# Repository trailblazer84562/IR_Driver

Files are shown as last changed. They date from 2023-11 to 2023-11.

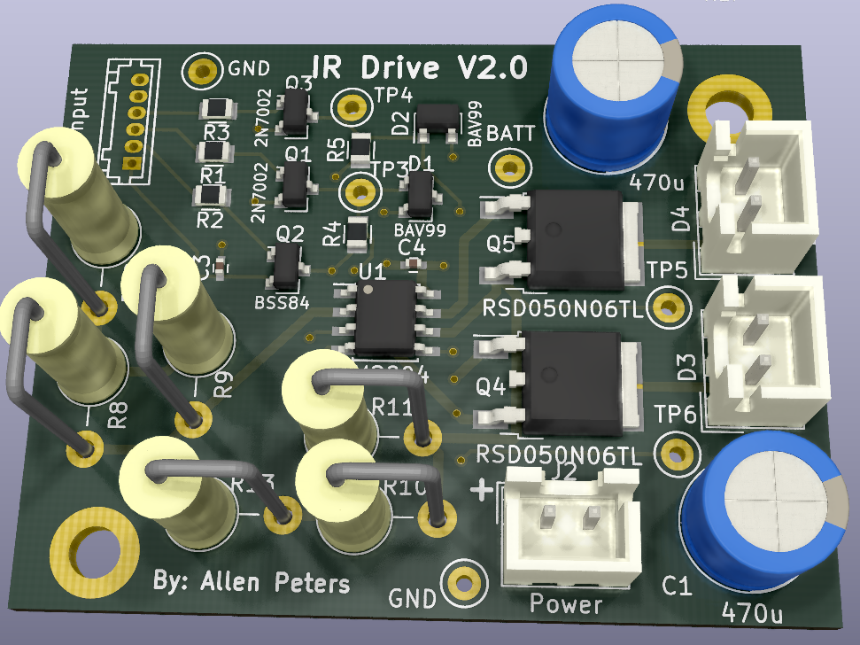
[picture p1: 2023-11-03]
EmitterDriverV2/EmitterV2.PNG

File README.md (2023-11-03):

# IR_Driver

<!-- Designed by Allen Peters

There are two design in here

The Emitter V2 is a dual IR driver
If I recall, the simulation and part selection is targetting ~0.9A
Works with 2S lipo, 6AA or 6NiMh batteries and performance should be voltage independent

The 360 IR TX and RX design is based off the Emitter V2
It targets a lower current (~200mA?) and drives 8 TSAL 7400 LEDs in a 360 degree pattern
It also has 4 IR receivers, also for a 360 degree pickup pattern -->

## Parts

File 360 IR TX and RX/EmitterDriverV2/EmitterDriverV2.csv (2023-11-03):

Source: | E:\Google Drive 2\KiCAD\Lantern Transmit Receive\EmitterDriverV2\EmitterDriverV2.kicad_sch
Date: | 7/3/2022 9:09:35 PM
Tool: | Eeschema (6.0.1)
Generator: | C:\Program Files\KiCad\6.0\bin\scripting\plugins/bom_csv_grouped_by_value.py
Component Count: | 50
Individual Components:
Item | Qty | Reference(s) | Value | LibPart | Footprint | Datasheet
 |  | C1 | 4.7u | Device:C | Capacitor_SMD:C_0805_2012Metric | ~
 |  | C2 | 470u | Device:CP | Capacitors_THT:CP_Radial_D8.0mm_P3.50mm
 |  | C3 | 2.2u | Device:C | Capacitors_SMD:C_0402 | ~
 |  | C4 | 2.2u | Device:C | Capacitors_SMD:C_0402 | ~
 |  | D1 | BAV99 | Diode:BAV99 | TO_SOT_Packages_SMD:SOT-23 | https://assets.nexperia.com/documents/data-sheet/BAV99_SER.pdf
 |  | D2 | BAV99 | Diode:BAV99 | TO_SOT_Packages_SMD:SOT-23 | https://assets.nexperia.com/documents/data-sheet/BAV99_SER.pdf
 |  | D3 | LED1 | Device:LED | LED_THT:LED_D5.0mm | ~
 |  | D4 | LED1 | Device:LED | LED_THT:LED_D5.0mm | ~
 |  | D5 | LED1 | Device:LED | LED_THT:LED_D5.0mm | ~
 |  | D6 | LED1 | Device:LED | LED_THT:LED_D5.0mm | ~
 |  | D7 | LED1 | Device:LED | LED_THT:LED_D5.0mm | ~
 |  | D8 | LED1 | Device:LED | LED_THT:LED_D5.0mm | ~
 |  | D9 | LED1 | Device:LED | LED_THT:LED_D5.0mm | ~
 |  | D10 | LED1 | Device:LED | LED_THT:LED_D5.0mm | ~
 |  | H1 | MountingHole | Mechanical:MountingHole | MountingHole:MountingHole_3.2mm_M3 | ~
 |  | H2 | MountingHole | Mechanical:MountingHole | MountingHole:MountingHole_3.2mm_M3 | ~
 |  | J1 | Input | Connector_Generic:Conn_01x06 | Connectors_Hirose:Hirose_DF13-06P-1.25DSA_06x1.25mm_Straight | ~
 |  | J2 | Power | Connector_Generic:Conn_01x02 | Connectors_JST:JST_XH_B02B-XH-A_02x2.50mm_Straight | ~
 |  | Q1 | 2N7002 | Transistor_FET:2N7002 | TO_SOT_Packages_SMD:SOT-23 | https://www.onsemi.com/pub/Collateral/NDS7002A-D.PDF
 |  | Q2 | BSS84 | Transistor_FET:BSS84 | TO_SOT_Packages_SMD:SOT-23 | http://assets.nexperia.com/documents/data-sheet/BSS84.pdf
 |  | Q3 | 2N7002 | Transistor_FET:2N7002 | TO_SOT_Packages_SMD:SOT-23 | https://www.onsemi.com/pub/Collateral/NDS7002A-D.PDF
 |  | Q4 | RSD050N06TL | Device:Q_NMOS_GDS | TO_SOT_Packages_SMD:TO-252-2 | ~
 |  | Q5 | RSD050N06TL | Device:Q_NMOS_GDS | TO_SOT_Packages_SMD:TO-252-2 | ~
 |  | R1 | 100 | Device:R | Resistor_SMD:R_0805_2012Metric | ~
 |  | R2 | 0 ohm | Device:R | Resistors_SMD:R_0805 | ~
 |  | R3 | 0 ohm | Device:R | Resistors_SMD:R_0805 | ~
 |  | R4 | 0 ohm | Device:R | Resistors_SMD:R_0805 | ~
 |  | R5 | 1k | Device:R | Resistors_SMD:R_0805 | ~
 |  | R6 | 1k | Device:R | Resistors_SMD:R_0805 | ~
 |  | R7 | 1k | Device:R | Resistors_SMD:R_0805 | ~
 |  | R8 | 1k | Device:R | Resistors_SMD:R_0805 | ~
 |  | R9 | 1 ohm | Device:R | Resistor_SMD:R_0805_2012Metric | ~
 |  | R10 | 1 ohm | Device:R | Resistor_SMD:R_0805_2012Metric | ~
 |  | R11 | 1 ohm | Device:R | Resistor_SMD:R_0805_2012Metric | ~
 |  | R12 | 1 ohm | Device:R | Resistor_SMD:R_0805_2012Metric | ~
 |  | R13 | 1 ohm | Device:R | Resistor_SMD:R_0805_2012Metric | ~
 |  | R14 | 1 ohm | Device:R | Resistor_SMD:R_0805_2012Metric | ~
 |  | TP1 | VBatt | Connector:TestPoint | TestPoint:TestPoint_Keystone_5000-5004_Miniature | ~
 |  | TP2 | GND | Connector:TestPoint | TestPoint:TestPoint_Keystone_5000-5004_Miniature | ~
 |  | TP3 | TX1Set | Connector:TestPoint | TestPoint:TestPoint_Keystone_5000-5004_Miniature | ~
 |  | TP4 | TX2Set | Connector:TestPoint | TestPoint:TestPoint_Keystone_5000-5004_Miniature | ~
 |  | TP5 | TX1FB | Connector:TestPoint | TestPoint:TestPoint_Keystone_5000-5004_Miniature | ~
 |  | TP6 | TX2FB | Connector:TestPoint | TestPoint:TestPoint_Keystone_5000-5004_Miniature | ~
 |  | TP7 | GND | Connector:TestPoint | TestPoint:TestPoint_Keystone_5000-5004_Miniature | ~
 |  | TP8 | RX | Connector:TestPoint | TestPoint:TestPoint_Keystone_5000-5004_Miniature | ~
 |  | U1 | TSOP4838 | Interface_Optical:TSOP45xx | OptoDevice:Vishay_MOLD-3Pin | http://www.vishay.com/docs/82460/tsop45.pdf
 |  | U2 | TSOP4838 | Interface_Optical:TSOP45xx | OptoDevice:Vishay_MOLD-3Pin | http://www.vishay.com/docs/82460/tsop45.pdf
 |  | U3 | TSOP4838 | Interface_Optical:TSOP45xx | OptoDevice:Vishay_MOLD-3Pin | http://www.vishay.com/docs/82460/tsop45.pdf
 |  | U4 | TSOP4838 | Interface_Optical:TSOP45xx | OptoDevice:Vishay_MOLD-3Pin | http://www.vishay.com/docs/82460/tsop45.pdf
 |  | U5 | LM2904 | Amplifier_Operational:LM2904 | Housings_SOIC:SOIC-8_3.9x4.9mm_Pitch1.27mm | http://www.ti.com/lit/ds/symlink/lm358.pdf
Collated Components:
Item | Qty | Reference(s) | Value | LibPart | Footprint | Datasheet
1 | 1 | C1 | 4.7u | Device:C | Capacitor_SMD:C_0805_2012Metric | ~
2 | 1 | C2 | 470u | Device:CP | Capacitors_THT:CP_Radial_D8.0mm_P3.50mm
3 | 2 | C3, C4 | 2.2u | Device:C | Capacitors_SMD:C_0402 | ~
4 | 2 | D1, D2 | BAV99 | Diode:BAV99 | TO_SOT_Packages_SMD:SOT-23 | https://assets.nexperia.com/documents/data-sheet/BAV99_SER.pdf
5 | 8 | D3, D4, D5, D6, D7, D8, D9, D10 | LED1 | Device:LED | LED_THT:LED_D5.0mm | ~
6 | 2 | H1, H2 | MountingHole | Mechanical:MountingHole | MountingHole:MountingHole_3.2mm_M3 | ~
7 | 1 | J1 | Input | Connector_Generic:Conn_01x06 | Connectors_Hirose:Hirose_DF13-06P-1.25DSA_06x1.25mm_Straight | ~
8 | 1 | J2 | Power | Connector_Generic:Conn_01x02 | Connectors_JST:JST_XH_B02B-XH-A_02x2.50mm_Straight | ~
9 | 2 | Q1, Q3 | 2N7002 | Transistor_FET:2N7002 | TO_SOT_Packages_SMD:SOT-23 | https://www.onsemi.com/pub/Collateral/NDS7002A-D.PDF
10 | 1 | Q2 | BSS84 | Transistor_FET:BSS84 | TO_SOT_Packages_SMD:SOT-23 | http://assets.nexperia.com/documents/data-sheet/BSS84.pdf
11 | 2 | Q4, Q5 | RSD050N06TL | Device:Q_NMOS_GDS | TO_SOT_Packages_SMD:TO-252-2 | ~
12 | 1 | R1 | 100 | Device:R | Resistor_SMD:R_0805_2012Metric | ~
13 | 3 | R2, R3, R4 | 0 ohm | Device:R | Resistors_SMD:R_0805 | ~
14 | 4 | R5, R6, R7, R8 | 1k | Device:R | Resistors_SMD:R_0805 | ~
15 | 6 | R9, R10, R11, R12, R13, R14 | 1 ohm | Device:R | Resistor_SMD:R_0805_2012Metric | ~
16 | 1 | TP1 | VBatt | Connector:TestPoint | TestPoint:TestPoint_Keystone_5000-5004_Miniature | ~
17 | 2 | TP2, TP7 | GND | Connector:TestPoint | TestPoint:TestPoint_Keystone_5000-5004_Miniature | ~
18 | 1 | TP3 | TX1Set | Connector:TestPoint | TestPoint:TestPoint_Keystone_5000-5004_Miniature | ~
19 | 1 | TP4 | TX2Set | Connector:TestPoint | TestPoint:TestPoint_Keystone_5000-5004_Miniature | ~
20 | 1 | TP5 | TX1FB | Connector:TestPoint | TestPoint:TestPoint_Keystone_5000-5004_Miniature | ~
21 | 1 | TP6 | TX2FB | Connector:TestPoint | TestPoint:TestPoint_Keystone_5000-5004_Miniature | ~
22 | 1 | TP8 | RX | Connector:TestPoint | TestPoint:TestPoint_Keystone_5000-5004_Miniature | ~
23 | 4 | U1, U2, U3, U4 | TSOP4838 | Interface_Optical:TSOP45xx | OptoDevice:Vishay_MOLD-3Pin | http://www.vishay.com/docs/82460/tsop45.pdf
24 | 1 | U5 | LM2904 | Amplifier_Operational:LM2904 | Housings_SOIC:SOIC-8_3.9x4.9mm_Pitch1.27mm | http://www.ti.com/lit/ds/symlink/lm358.pdf

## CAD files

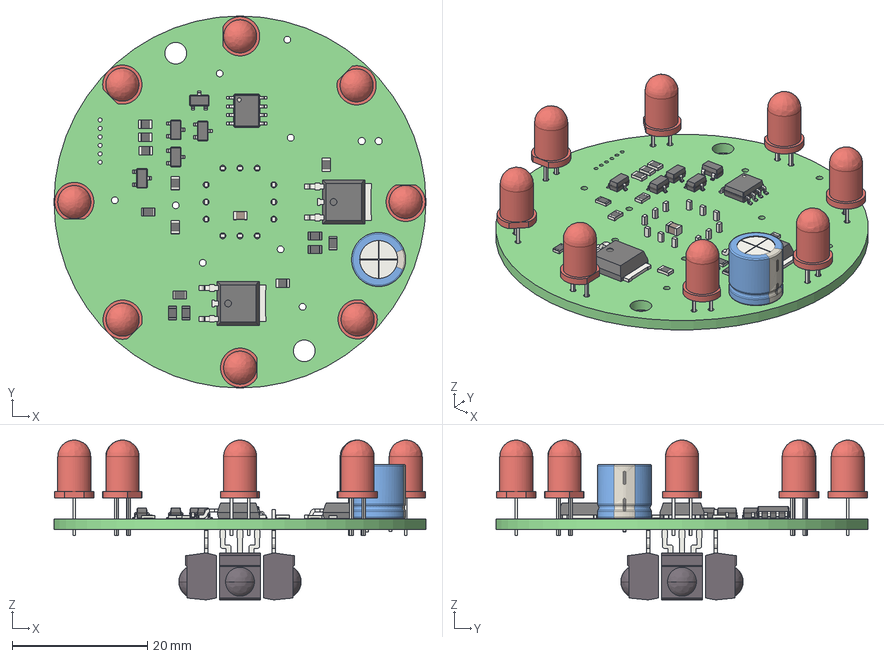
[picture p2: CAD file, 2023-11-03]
360 IR TX and RX/EmitterDriverV2/EmitterDriverV2.step
55.0 x 55.0 x 23.6 mm
EmitterDriverV2 PCB

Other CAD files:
360 IR TX and RX/EmitterDriverV2/EmitterDriverV2.ipt

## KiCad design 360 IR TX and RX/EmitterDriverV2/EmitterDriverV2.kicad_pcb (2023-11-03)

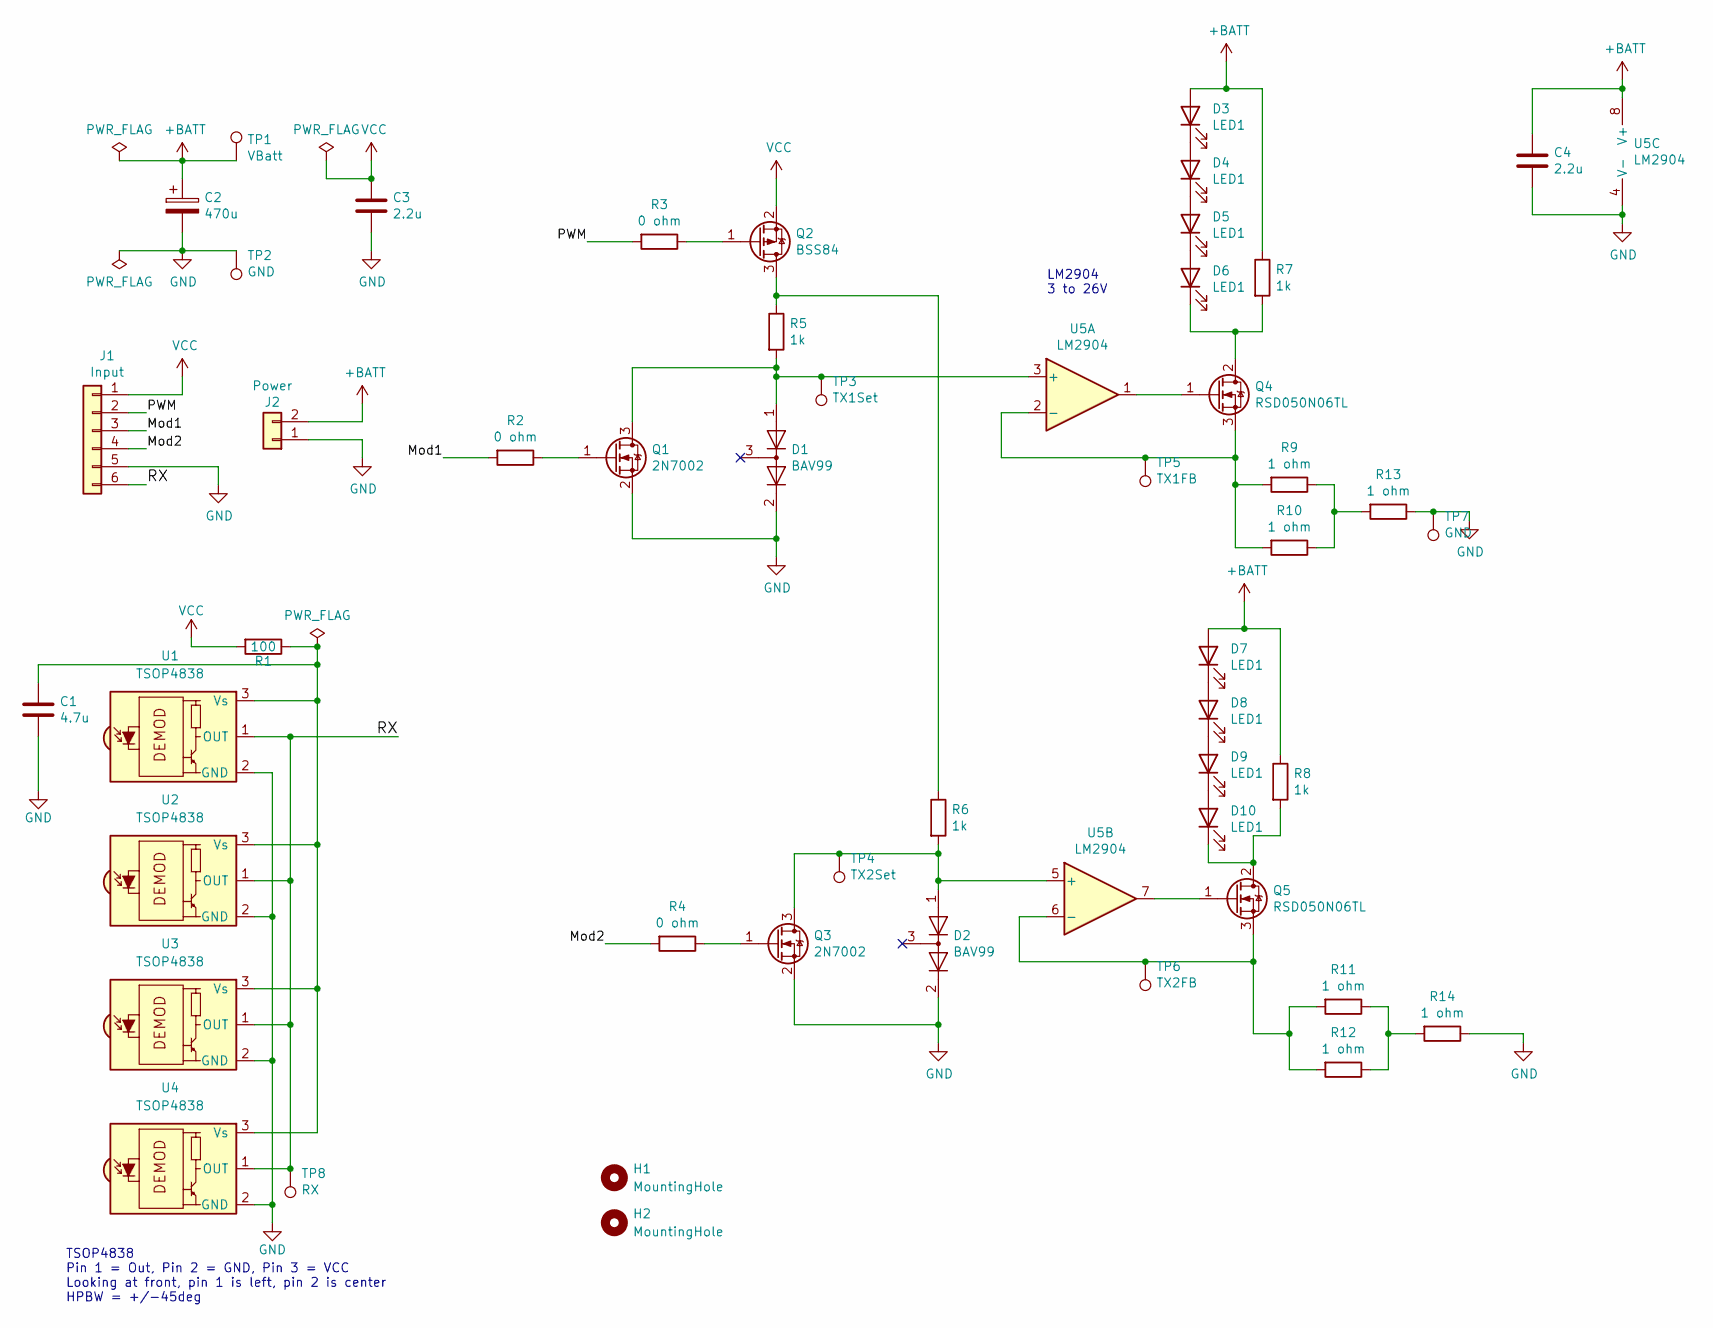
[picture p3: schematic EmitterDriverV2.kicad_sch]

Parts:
C1: 4.7u; C_0805_2012Metric
C2: 470u; CP_Radial_D8.0mm_P3.50mm
C3, C4: 2.2u; C_0402
D1, D2: BAV99; SOT-23
D3, D4, D5, D6, D7, D8, D9, D10: LED1; LED_D5.0mm
H1, H2: MountingHole; MountingHole_3.2mm_M3
J1: Input; Hirose_DF13-06P-1.25DSA_06x1.25mm_Straight
J2: Power; JST_XH_B02B-XH-A_02x2.50mm_Straight
Q1, Q3: 2N7002; SOT-23
Q2: BSS84; SOT-23
Q4, Q5: RSD050N06TL; TO-252-2
R1: 100; R_0805_2012Metric
R2, R3, R4: 0 ohm; R_0805
R5, R6, R7, R8: 1k; R_0805
R9, R10, R11, R12, R13, R14: 1 ohm; R_0805_2012Metric
TP1: VBatt; TestPoint_Keystone_5000-5004_Miniature
TP2, TP7: GND; TestPoint_Keystone_5000-5004_Miniature
TP3: TX1Set; TestPoint_Keystone_5000-5004_Miniature
TP4: TX2Set; TestPoint_Keystone_5000-5004_Miniature
TP5: TX1FB; TestPoint_Keystone_5000-5004_Miniature
TP6: TX2FB; TestPoint_Keystone_5000-5004_Miniature
TP8: RX; TestPoint_Keystone_5000-5004_Miniature
U1, U2, U3, U4: TSOP4838; Vishay_MOLD-3Pin
U5: LM2904; SOIC-8_3.9x4.9mm_Pitch1.27mm

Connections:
+BATT: C2.1, C4.1, D3.2 (A), D7.2 (A), J2.2, R7.1, R8.1, TP1.1, U5.8 (V+)
/Mod1: J1.3, R2.2
/Mod2: J1.4, R4.2
/PWM: J1.2, R3.2
/RX: J1.6, TP8.1, U1.1 (OUT), U2.1 (OUT), U3.1 (OUT), U4.1 (OUT)
GND: C1.2, C2.2, C3.2, C4.2, D1.2 (A), D2.2 (A), J1.5, J2.1, Q1.2 (S), Q3.2 (S), R13.1, R14.1, TP2.1, TP7.1, U1.2 (GND), U2.2 (GND), U3.2 (GND), U4.2 (GND), U5.4 (V-)
unnamed: C1.1, R1.1, U1.3 (Vs), U2.3 (Vs), U3.3 (Vs), U4.3 (Vs)
unnamed: D1.1 (K), Q1.3 (D), R5.2, TP3.1, U5.3 (+)
unnamed: D2.1 (K), Q3.3 (D), R6.2, TP4.1, U5.5 (+)
unnamed: D3.1 (K), D4.2 (A)
unnamed: D4.1 (K), D5.2 (A)
unnamed: D5.1 (K), D6.2 (A)
unnamed: D6.1 (K), Q4.2 (D), R7.2
unnamed: D7.1 (K), D8.2 (A)
unnamed: D8.1 (K), D9.2 (A)
unnamed: D10.1 (K), Q5.2 (D), R8.2
unnamed: D9.1 (K), D10.2 (A)
unnamed: Q1.1 (G), R2.1
unnamed: Q2.1 (G), R3.1
unnamed: Q2.3 (D), R5.1, R6.1
unnamed: Q3.1 (G), R4.1
unnamed: Q4.1 (G), U5.1
unnamed: Q4.3 (S), R9.2, R10.2, TP5.1, U5.2 (-)
unnamed: Q5.1 (G), U5.7
unnamed: Q5.3 (S), R11.2, R12.2, TP6.1, U5.6 (-)
unnamed: R9.1, R10.1, R13.2
unnamed: R11.1, R12.1, R14.2
VCC: C3.1, J1.1, Q2.2 (S), R1.2

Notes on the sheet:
TSOP4838 Pin 1 = Out, Pin 2 = GND, Pin 3 = VCC Looking at front, pin 1 is left, pin 2 is center HPBW = +/-45deg
LM2904 3 to 26V

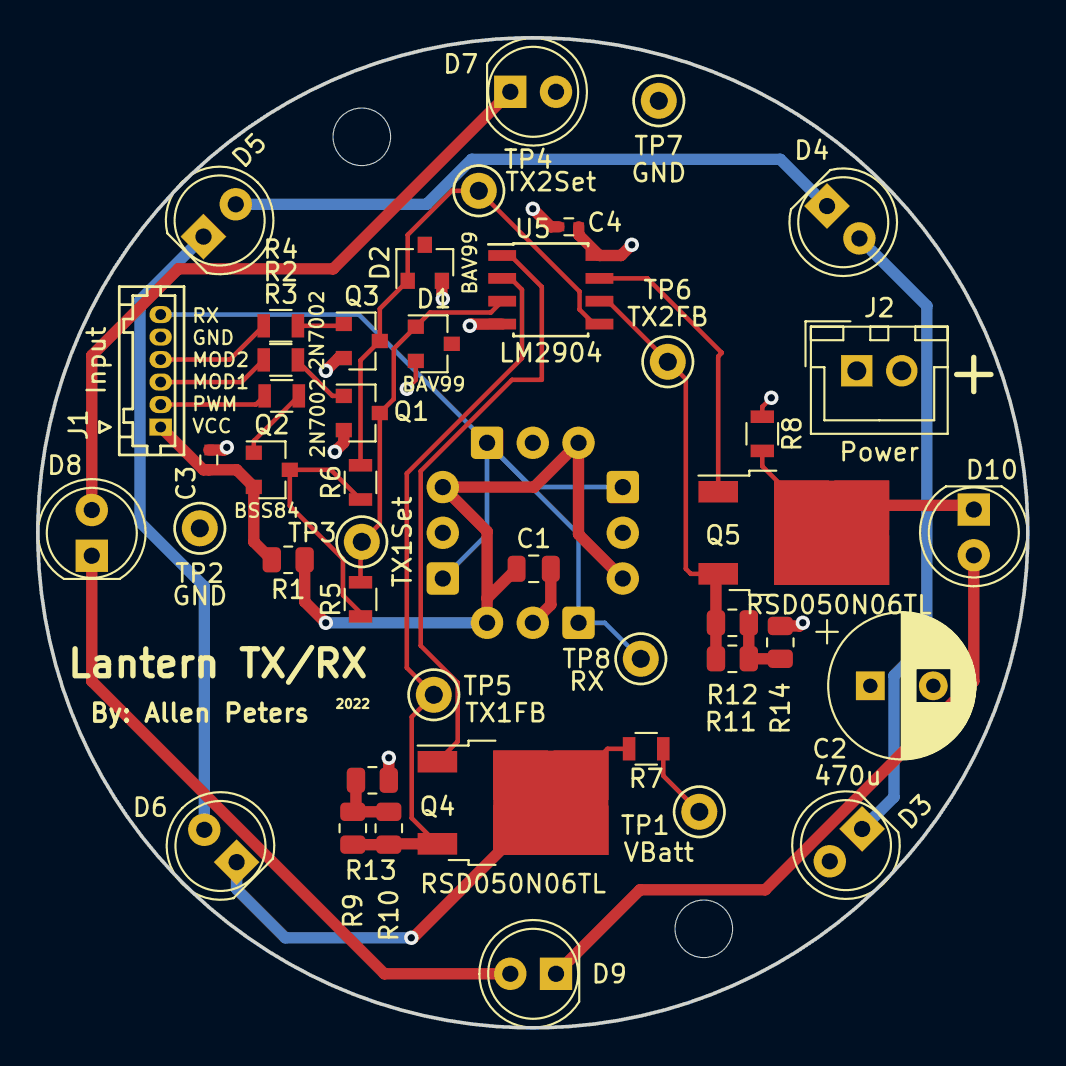
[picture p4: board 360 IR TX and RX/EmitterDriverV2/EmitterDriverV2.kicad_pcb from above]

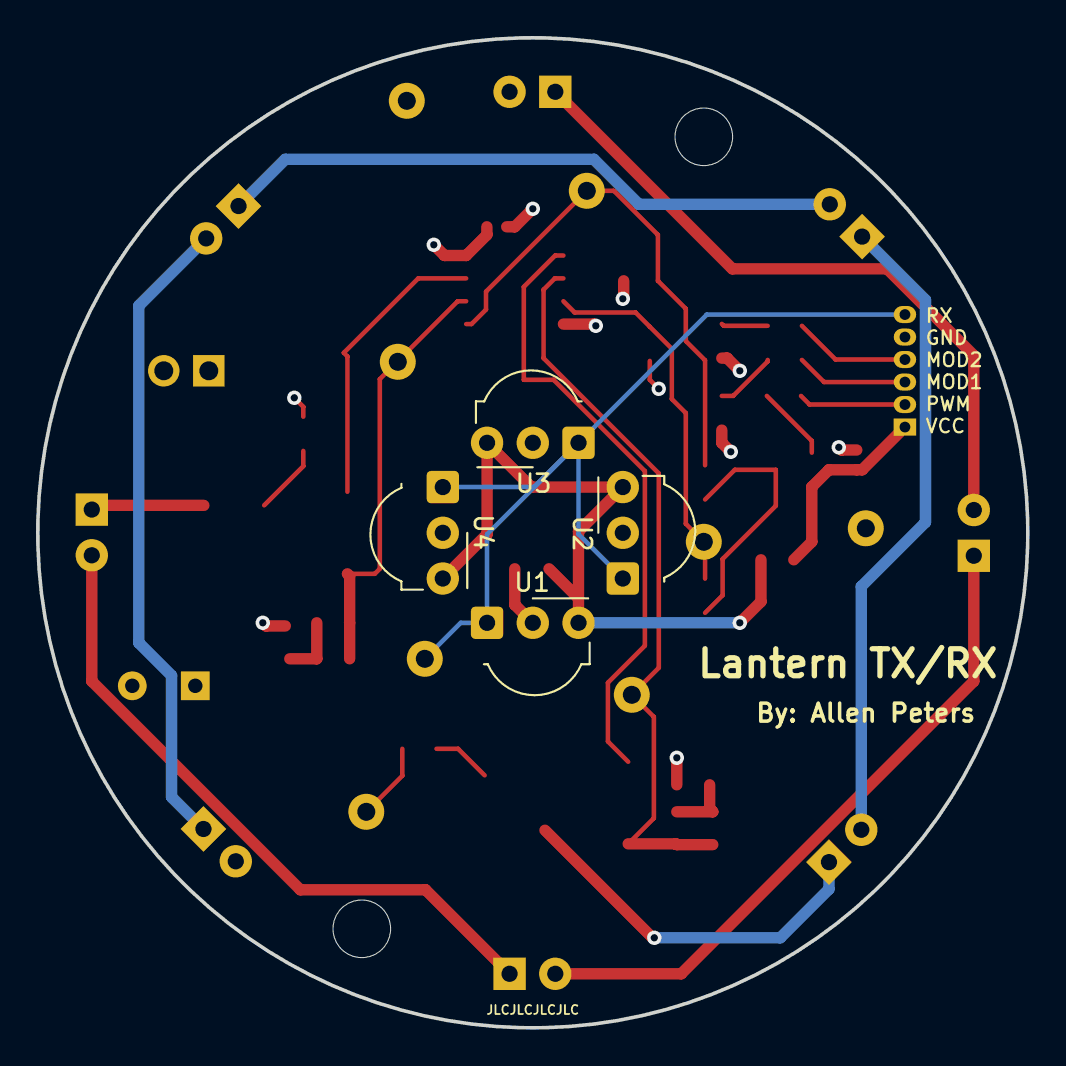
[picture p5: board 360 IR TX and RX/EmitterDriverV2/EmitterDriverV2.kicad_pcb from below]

Board: 4 copper layers, 55.0 x 55.0 mm, 50 parts (4 on the bottom side), 28 nets.

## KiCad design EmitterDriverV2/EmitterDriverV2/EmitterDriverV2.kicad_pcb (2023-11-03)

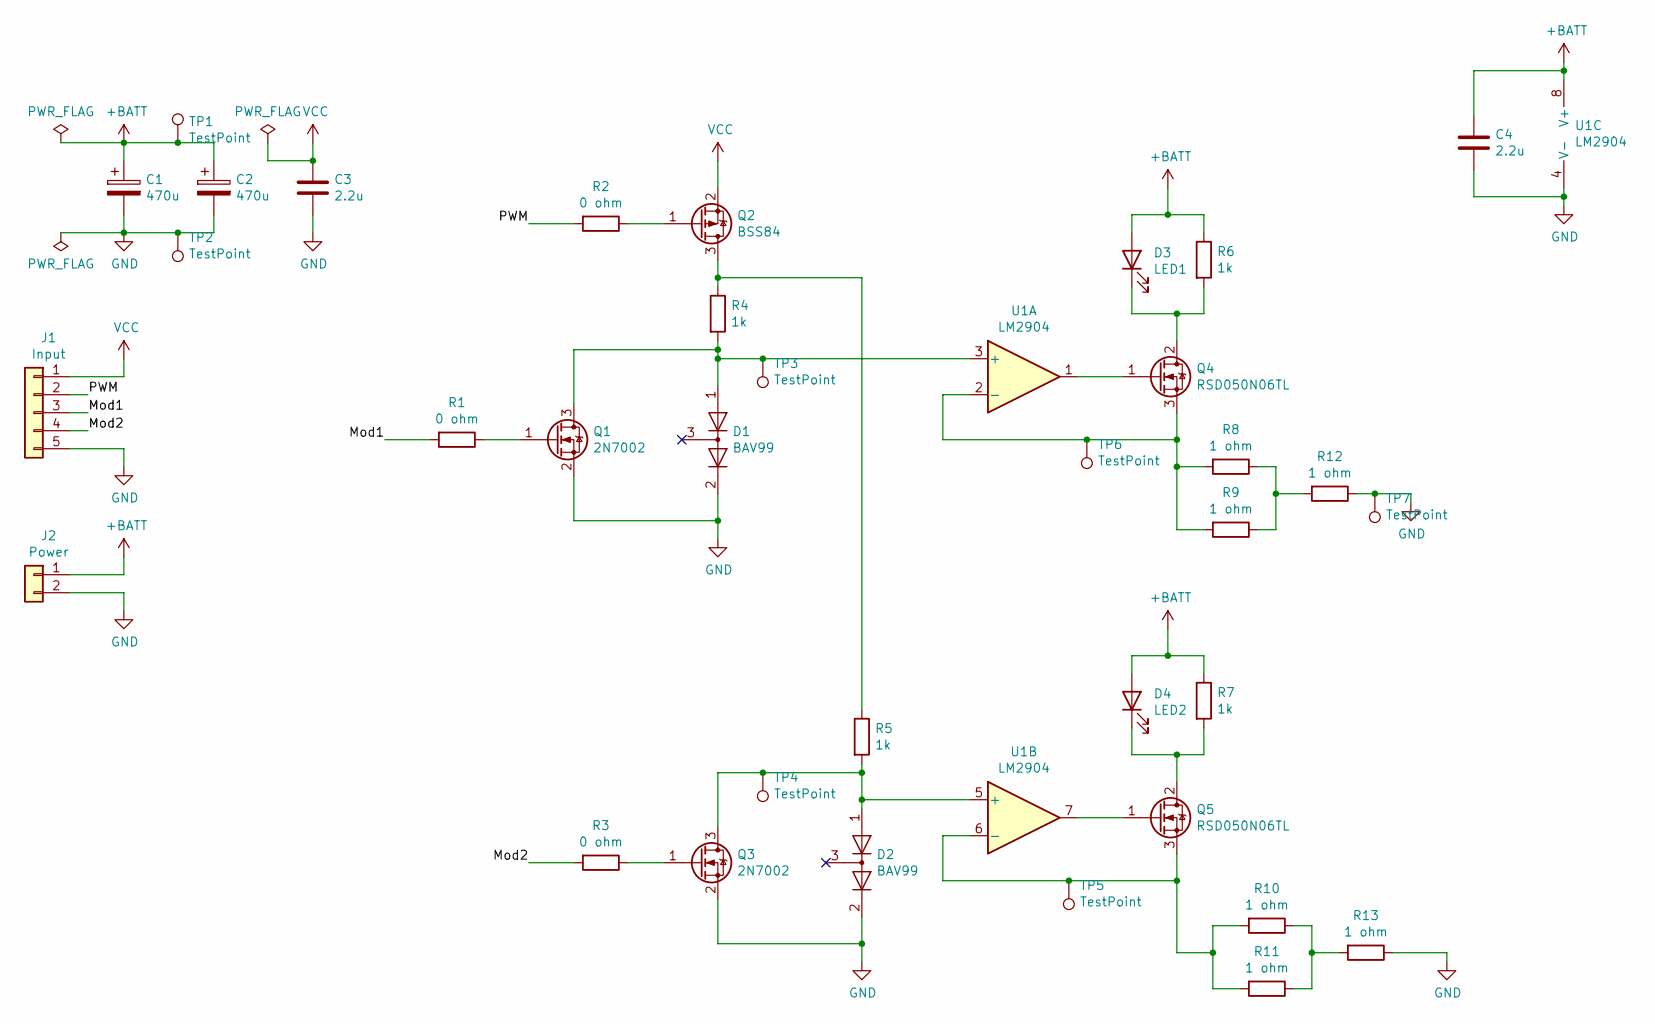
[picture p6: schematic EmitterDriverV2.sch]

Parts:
C1, C2: 470u; CP_Radial_D8.0mm_P3.50mm
C3, C4: 2.2u; C_0402
D1, D2: BAV99; SOT-23
D3: LED1; JST_XH_B02B-XH-A_02x2.50mm_Straight
D4: LED2; JST_XH_B02B-XH-A_02x2.50mm_Straight
J1: Input; Hirose_DF13-06P-1.25DSA_06x1.25mm_Straight
J2: Power; JST_XH_B02B-XH-A_02x2.50mm_Straight
Q1, Q3: 2N7002; SOT-23
Q2: BSS84; SOT-23
Q4, Q5: RSD050N06TL; TO-252-2
R1, R2, R3: 0 ohm; R_0805
R4, R5, R6, R7: 1k; R_0805
R8, R9, R10, R11, R12, R13: 1 ohm; R_Axial_DIN0414_L11.9mm_D4.5mm_P5.08mm_Vertical
TP1, TP2, TP3, TP4, TP5, TP6, TP7: TestPoint; Test_Point_Keystone_5000-5004_Miniature
U1: LM2904; SOIC-8_3.9x4.9mm_Pitch1.27mm

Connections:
+BATT: C1.1, C2.1, C4.1, D3.2 (A), D4.2 (A), J2.1, R6.1, R7.1, TP1.1, U1.8 (V+); also elsewhere on the board
/Mod1: J1.3, R1.2
/Mod2: J1.4, R3.2
/PWM: J1.2, R2.2
GND: C1.2, C2.2, C3.2, C4.2, D1.2 (A), D2.2 (A), J1.5, J2.2, Q1.2 (S), Q3.2 (S), R12.1, R13.1, TP2.1, TP7.1, U1.4 (V-); also elsewhere on the board
unnamed: D1.1 (K), Q1.3 (D), R4.2, TP3.1, U1.3 (+)
unnamed: D2.1 (K), Q3.3 (D), R5.2, TP4.1, U1.5 (+)
unnamed: D3.1 (K), Q4.2 (D), R6.2
unnamed: D4.1 (K), Q5.2 (D), R7.2
unnamed: Q1.1 (G), R1.1
unnamed: Q2.1 (G), R2.1
unnamed: Q2.3 (D), R4.1, R5.1
unnamed: Q3.1 (G), R3.1
unnamed: Q4.1 (G), U1.1
unnamed: Q4.3 (S), R8.2, R9.2, TP6.1, U1.2 (-)
unnamed: Q5.1 (G), U1.7
unnamed: Q5.3 (S), R10.2, R11.2, TP5.1, U1.6 (-)
unnamed: R10.1, R11.1, R13.2
unnamed: R8.1, R9.1, R12.2
VCC: C3.1, J1.1, Q2.2 (S)

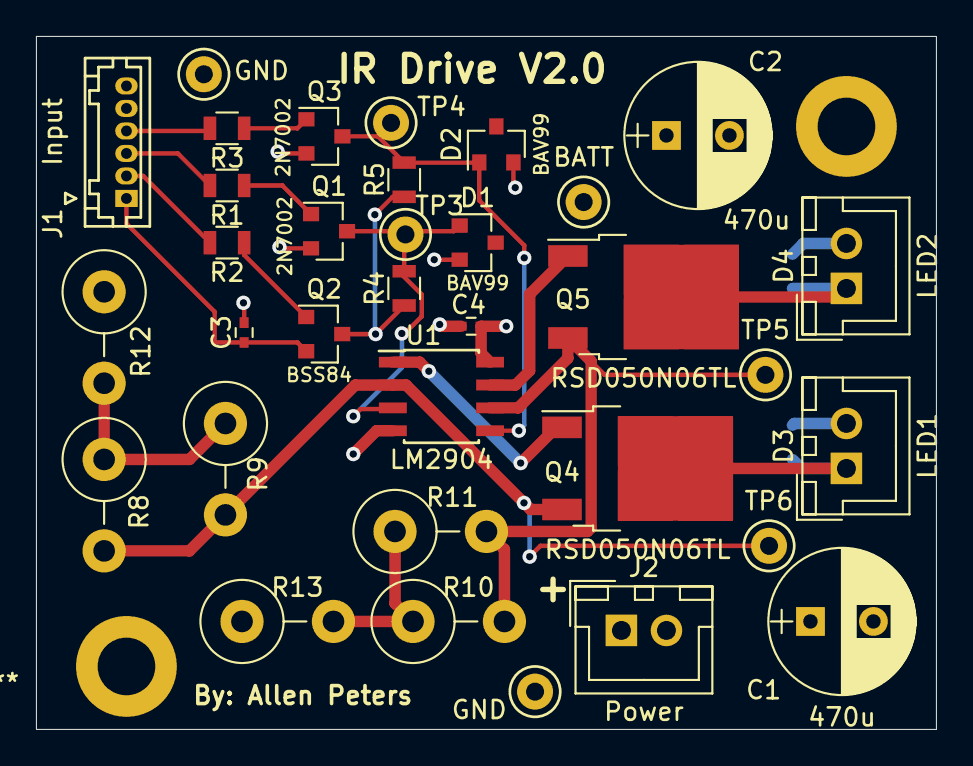
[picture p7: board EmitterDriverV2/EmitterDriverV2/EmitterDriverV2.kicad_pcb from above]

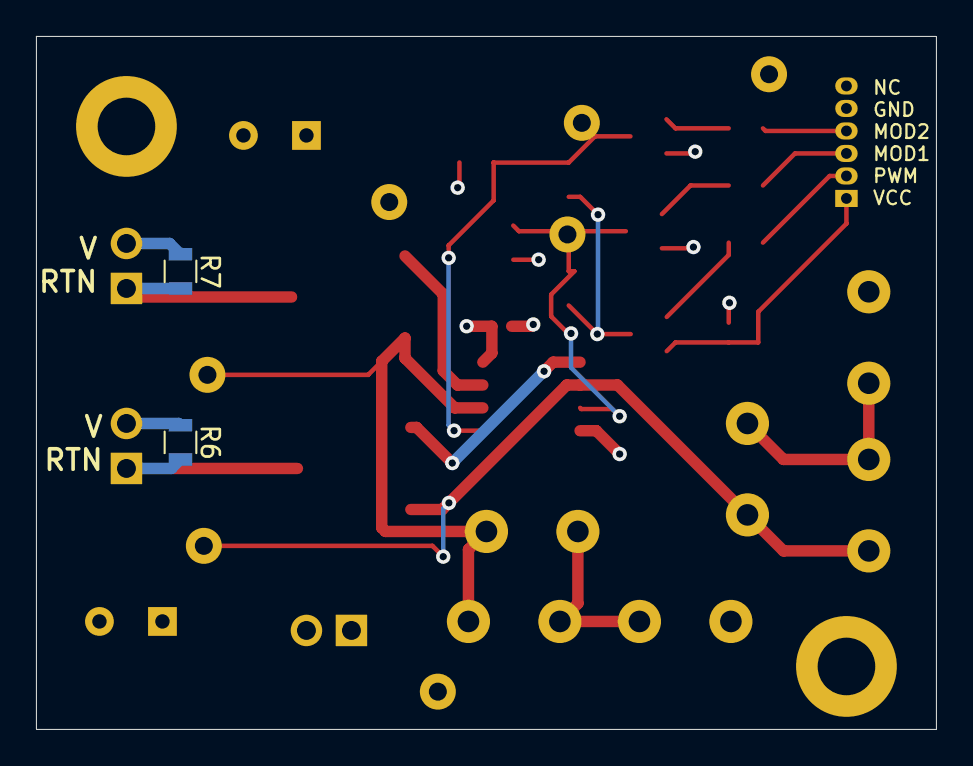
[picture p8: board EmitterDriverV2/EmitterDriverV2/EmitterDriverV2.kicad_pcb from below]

Board: 4 copper layers, 50.0 x 38.5 mm, 36 parts (2 on the bottom side), 20 nets.

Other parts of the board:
BATT: TestPoint; Test_Point_Keystone_5000-5004_Miniature
GND: TestPoint; Test_Point_Keystone_5000-5004_Miniature
GND#2: TestPoint; Test_Point_Keystone_5000-5004_Miniature

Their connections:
+BATT: BATT.1; also elsewhere on the board
GND: GND.1, GND#2.1; also elsewhere on the board
